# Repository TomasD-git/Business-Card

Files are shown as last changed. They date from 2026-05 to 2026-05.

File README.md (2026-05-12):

# Business-Card

> A custom dev board built inside a business card — NFC, e-paper display and 16 exposed GPIO pins.



---

## Features

- E-paper display — Configure once image stays
- NFC — tap to share Contact info, a URL, or any custom NFC
- 16 exposed GPIO pins — Connector makes it easy to use for another project
- No power design - Once flashed and configured, nfc works with no external power and image stays on e-paper screen

---

## How It Works

The Business Card is a fully custom PCB designed. The microcontroller drives both the e-paper display and the NFC IC over SPI/I2C, while the 16 GPIO pins are broken out along one edge for easy prototyping.

On power-up, the firmware initialises the display and NFC tag, can be configured, the e-paper holds whatever was last written without needing a continuous refresh.

---

## Schematic Overview

The schematic is split into four main blocks:



**MCU**: Core microcontroller, configuration of nfc and e-paper, GPIO pins   
**E-paper interface**: Has 8 exposed pins to solder an E-paper onto the PCB  
**NFC**: NFC IC with antenna matching network, presents as a standard NDEF tag  
**Power**: Power regulation with decoupling  

---

## PCB

Designed in KiCad, manufactured as a standard 2-layer board with PCBA. Gerber files and BOM are in the repo if you want to order your own.



---

<details>
  <summary>BOM</summary>

| Name | Purpose | Quantity | Total Cost (USD) | Link | Distributor |
|---|---|---|---|---|---|
| locknut | secures the screen in place with M2 bolts | 1 | 4.88 | [Link](https://www.aliexpress.com/item/32963044301.html) | Aliexpress |
| PCB + PCBA | PCB with PCBA | 2 | 73.27 | [Link](https://jlcpcb.com) | jlcpcb |
| E-Paper, 2.13" | Screen to see my name | 1 | 12.44 | [Link](https://www.aliexpress.com/item/1005005183232092.html) | Aliexpress |

</details>

<details>
  <summary>For Future</summary>

## Planned improvements

**User interface**    
Change firmware so it could be configured with web or custom application.  

**Custom CAD**  
Some type of CAD to protect mcu.  

</details>

<details>
  <summary>License</summary>

### MIT License

**Copyright (c) [2026] [TomasD-git]**

Permission is hereby granted, free of charge, to any person obtaining a copy
of this software and associated documentation files (the "Software"), to deal
in the Software without restriction, including without limitation the rights
to use, copy, modify, merge, publish, distribute, sublicense, and/or sell
copies of the Software, and to permit persons to whom the Software is
furnished to do so, subject to the following conditions:

The above copyright notice and this permission notice shall be included in all
copies or substantial portions of the Software.

THE SOFTWARE IS PROVIDED "AS IS", WITHOUT WARRANTY OF ANY KIND, EXPRESS OR
IMPLIED, INCLUDING BUT NOT LIMITED TO THE WARRANTIES OF MERCHANTABILITY,
FITNESS FOR A PARTICULAR PURPOSE AND NONINFRINGEMENT. IN NO EVENT SHALL THE
AUTHORS OR COPYRIGHT HOLDERS BE LIABLE FOR ANY CLAIM, DAMAGES OR OTHER
LIABILITY, WHETHER IN AN ACTION OF CONTRACT, TORT OR OTHERWISE, ARISING FROM,
OUT OF OR IN CONNECTION WITH THE SOFTWARE OR THE USE OR OTHER DEALINGS IN THE
SOFTWARE.

</details>

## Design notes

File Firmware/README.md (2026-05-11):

## Here you will find all firmware related stuff  
## Down here are instructions to flash the stm32  

To flash it via **usb-c** u first need to put it into **bootloader** mode, you can achive that by pluggin it in while holding boot button.  
Once in bootloader mode open **STM32CubeProgrammer**, and click connect and connect the board.  
Now pretty much done upload the **.bin** file there and flash.  

To know if it flashed sucesfully theres a small blue LED that will blink if flashed sucesfully.
Thats all.

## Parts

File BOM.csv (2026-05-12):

Name | Purpose | Quantity | Total Cost (USD) | Link | Distributor
locknut | secures the screen in place with M2 bolts | 1 | 4.88 | https://www.aliexpress.com/item/32963044301.html | Aliexpress
PCB + PCBA | PCB with PCBA | 2 | 73.27 | https://jlcpcb.com | jlcpcb
E-Paper, 2.13" | Screen to see my name | 1 | 12.44 | https://www.aliexpress.com/item/1005005183232092.html | Aliexpress

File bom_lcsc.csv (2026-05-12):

Designator | Footprint | Quantity | Value | LCSC Part #
BOOT0, NRST | SW_Push_1P1T_XKB_TS-1187A | 2 | SW_Push | C318884
C1, C3, C9 | 0402 | 3 | 1uF | C52923
C10, C11, C6 | 0603 | 3 | 10uF | C19702
C12, C13, C2, C4, C5, C7, C8 | 0402 | 7 | 100nF | C1525
D1 | 0402 | 1 | GREEN LED | C74338
D2 | 0402 | 1 | BLUE LED | C131223
J2, J3 | PinHeader_1x04_P2.54mm_Vertical | 2 | Conn_01x04_Pin
J4 | PinHeader_1x02_P2.54mm_Vertical | 1 | Conn_01x02_Pin
J5, J6 | PinSocket_1x10_P2.54mm_Vertical | 2 | Conn_01x10_Socket
J7 | USB_C_Receptacle_XKB_U262-16XN-4BVC11 | 1 | USB_C_Receptacle_USB2.0_16P | C319148
L1 | COIL_GENERATOR | 1 | L
R1, R2 | 0402 | 2 | 5.1K | C25905
R11 | 0402 | 1 | 330 | C25104
R12 | 0402 | 1 | 68 | C25758
R3, R4 | 0402 | 2 | 22 | C25092
R5, R8 | 0402 | 2 | 10K | C25744
R6, R7 | 0402 | 2 | 4.7K | C25900
U1 | QFN8P50_160X160X50L40X20N | 1 | NT3H2111W0FHKH | C710403
U2 | SOT-23-5 | 1 | AP2112K-3.3 | C51118
U3 | LQFP-48_7x7mm_P0.5mm | 1 | STM32F072C8Tx | C80488

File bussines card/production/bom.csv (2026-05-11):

Designator | Footprint | Quantity | Value | LCSC Part #
BOOT0, NRST | SW_Push_1P1T_XKB_TS-1187A | 2 | SW_Push
C1, C3, C9 | 0402 | 3 | 1uf
C10, C11, C6 | 0603 | 3 | 10uf
C12, C13, C2, C4, C5, C7, C8 | 0402 | 7 | 100nf
D1 | 0402 | 1 | GREEN LED
D2 | 0402 | 1 | BLUE LED
J2, J3 | PinHeader_1x04_P2.54mm_Vertical | 2 | Conn_01x04_Pin
J4 | PinHeader_1x02_P2.54mm_Vertical | 1 | Conn_01x02_Pin
J5, J6 | PinSocket_1x10_P2.54mm_Vertical | 2 | Conn_01x10_Socket
J7 | USB_C_Receptacle_XKB_U262-16XN-4BVC11 | 1 | USB_C_Receptacle_USB2.0_16P
L1 | COIL_GENERATOR | 1 | L
R1, R2 | 0402 | 2 | 5.1K
R11 | 0402 | 1 | 330
R12 | 0402 | 1 | 68
R3, R4 | 0402 | 2 | 22
R5, R8 | 0402 | 2 | 10K
R6, R7 | 0402 | 2 | 4.7K
U1 | QFN8P50_160X160X50L40X20N | 1 | NT3H2111W0FHKH
U2 | SOT-23-5 | 1 | AP2112K-3.3
U3 | LQFP-48_7x7mm_P0.5mm | 1 | STM32F072C8Tx

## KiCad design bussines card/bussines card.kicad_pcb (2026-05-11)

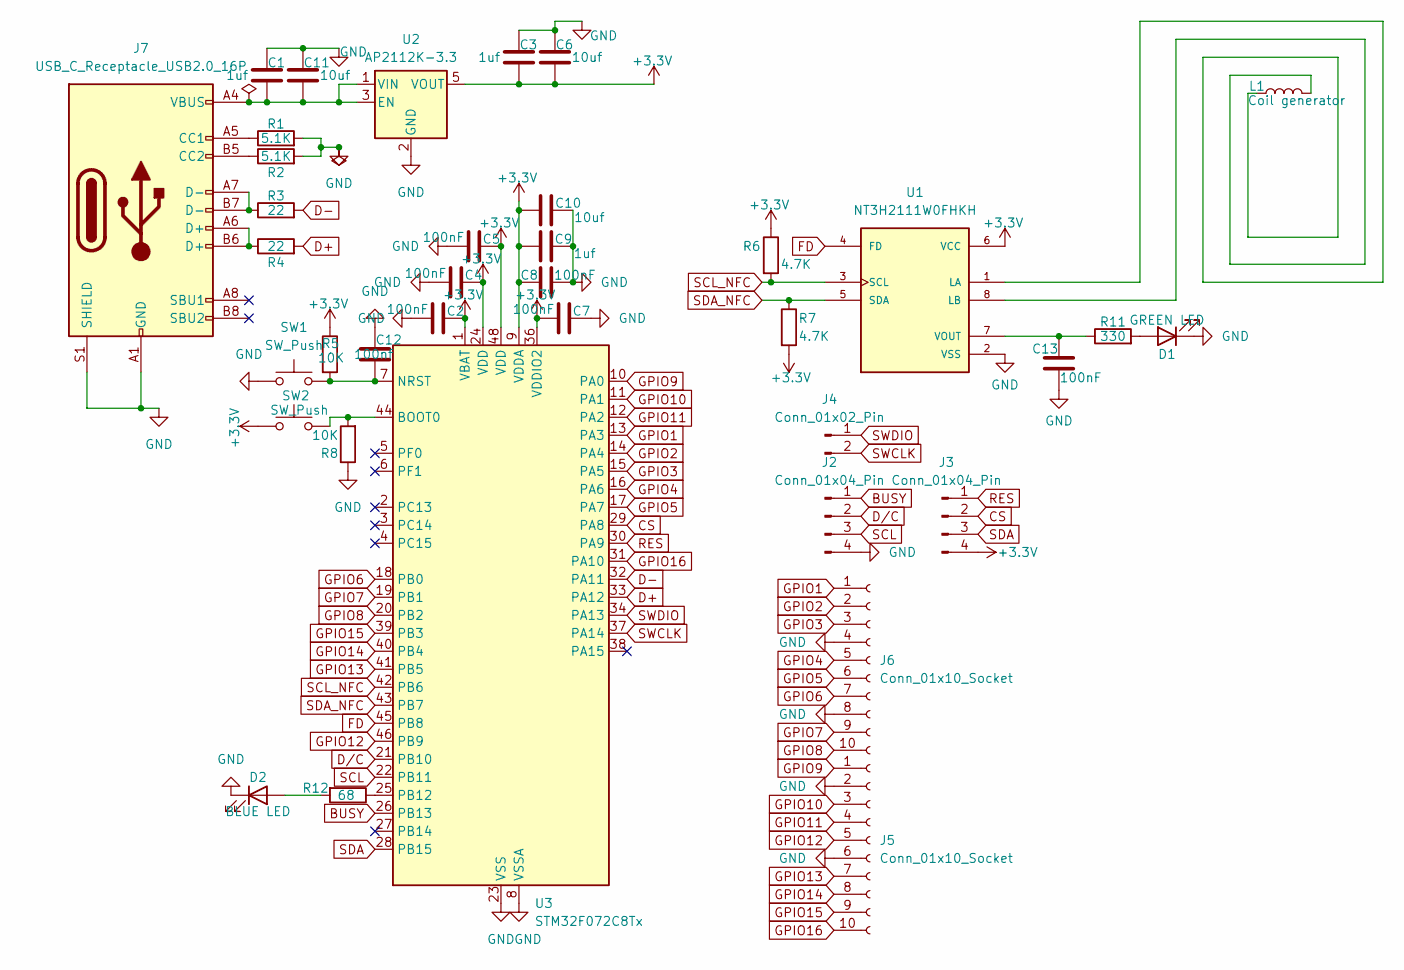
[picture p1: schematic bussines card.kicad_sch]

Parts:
C1, C3, C9: 1uf; C_0402_1005Metric
C2, C4, C5, C7, C8, C13: 100nF; C_0402_1005Metric
C6, C10, C11: 10uf; C_0603_1608Metric
C12: 100nf; C_0402_1005Metric
D1: GREEN LED; LED_0402_1005Metric
D2: BLUE LED; LED_0402_1005Metric
J2, J3: Conn_01x04_Pin; PinHeader_1x04_P2.54mm_Vertical
J4: Conn_01x02_Pin; PinHeader_1x02_P2.54mm_Vertical
J5, J6: Conn_01x10_Socket; PinSocket_1x10_P2.54mm_Vertical
J7: USB_C_Receptacle_USB2.0_16P; USB_C_Receptacle_XKB_U262-16XN-4BVC11
L1: Coil generator; COIL_GENERATOR
R1, R2: 5.1K; R_0402_1005Metric
R3, R4: 22; R_0402_1005Metric
R5, R8: 10K; R_0402_1005Metric
R6, R7: 4.7K; R_0402_1005Metric
R11: 330; R_0402_1005Metric
R12: 68; R_0402_1005Metric
SW1, SW2: SW_Push; SW_Push_1P1T_XKB_TS-1187A
U1: NT3H2111W0FHKH; QFN8P50_160X160X50L40X20N
U2: AP2112K-3.3; SOT-23-5
U3: STM32F072C8Tx; LQFP-48_7x7mm_P0.5mm

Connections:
+3.3V: C2.2, C3.2, C4.2, C5.2, C6.2, C7.1, C8.1, C9.1, C10.1, J3.4, R5.1, R6.1, R7.2, SW2.1, U1.6 (VCC), U2.5 (VOUT), U3.1 (VBAT), U3.9 (VDDA), U3.24 (VDD), U3.36 (VDDIO2), U3.48 (VDD); also elsewhere on the board
BUSY: J2.1, U3.26 (PB13)
CS: J3.2, U3.29 (PA8)
D+: R4.2, U3.33 (PA12)
D-: R3.2, U3.32 (PA11)
D/C: J2.2, U3.21 (PB10)
FD: U1.4 (FD), U3.45 (PB8)
GND: C1.1, C2.1, C3.1, C4.1, C5.1, C6.1, C7.2, C8.2, C9.2, C10.2, C11.1, C12.1, C13.1, D1.1 (K), D2.1 (K), J2.4, J5.2, J5.6, J6.4, J6.8, J7.A1 (GND), J7.A12 (GND), J7.B1 (GND), J7.B12 (GND), J7.S1 (SHIELD), R1.2, R2.2, R8.1, SW1.1, U1.2 (VSS), U2.2 (GND), U3.8 (VSSA), U3.23 (VSS), U3.35 (VSS), U3.47 (VSS); also elsewhere on the board
GPIO1: J6.1, U3.13 (PA3)
GPIO2: J6.2, U3.14 (PA4)
GPIO3: J6.3, U3.15 (PA5)
GPIO4: J6.5, U3.16 (PA6)
GPIO5: J6.6, U3.17 (PA7)
GPIO6: J6.7, U3.18 (PB0)
GPIO7: J6.9, U3.19 (PB1)
GPIO8: J6.10, U3.20 (PB2)
GPIO9: J5.1, U3.10 (PA0)
GPIO10: J5.3, U3.11 (PA1)
GPIO11: J5.4, U3.12 (PA2)
GPIO12: J5.5, U3.46 (PB9)
GPIO13: J5.7, U3.41 (PB5)
GPIO14: J5.8, U3.40 (PB4)
GPIO15: J5.9, U3.39 (PB3)
GPIO16: J5.10, U3.31 (PA10)
unnamed: D1.2 (A), R11.2
unnamed: D2.2 (A), R12.2
unnamed: J7.A5 (CC1), R1.1
unnamed: J7.B5 (CC2), R2.1
unnamed: J7.A6 (D+), J7.B6 (D+), R4.1
unnamed: J7.A7 (D-), J7.B7 (D-), R3.1
unnamed: L1.1, U1.1 (LA)
unnamed: L1.2, U1.8 (LB)
unnamed: C13.2, R11.1, U1.7 (VOUT)
unnamed: C1.2, C11.2, J7.A4 (VBUS), J7.A9 (VBUS), J7.B4 (VBUS), J7.B9 (VBUS), U2.1 (VIN), U2.3 (EN)
unnamed 34: R8.2, SW2.2, U3.44 (BOOT0); also elsewhere on the board
unnamed 35: C12.2, R5.2, SW1.2, U3.7 (NRST); also elsewhere on the board
unnamed: R12.1, U3.25 (PB12)
RES: J3.1, U3.30 (PA9)
SCL: J2.3, U3.22 (PB11)
SCL_NFC: R6.2, U1.3 (SCL), U3.42 (PB6)
SDA: J3.3, U3.28 (PB15)
SDA_NFC: R7.1, U1.5 (SDA), U3.43 (PB7)
SWCLK: J4.2, U3.37 (PA14)
SWDIO: J4.1, U3.34 (PA13)

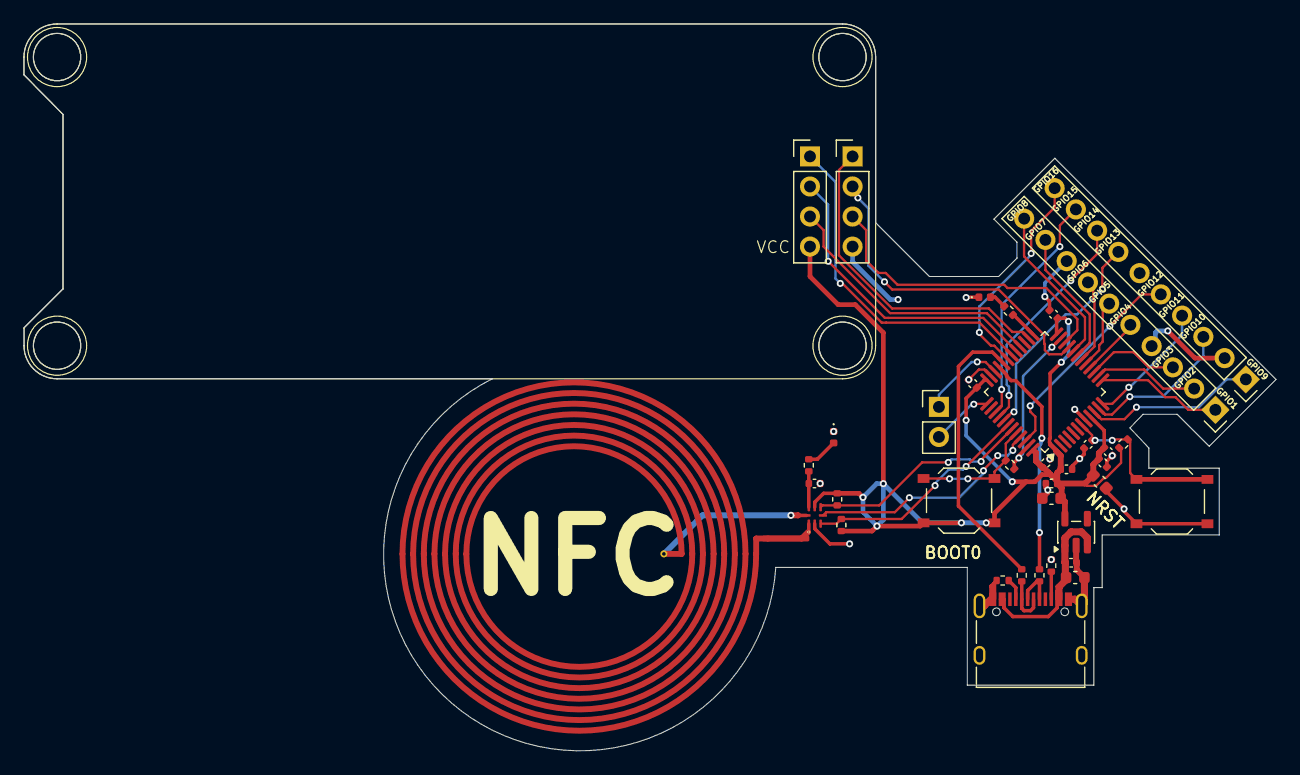
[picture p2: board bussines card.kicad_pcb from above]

Board: 2 copper layers, 105.9 x 61.4 mm, 37 parts (0 on the bottom side), 44 nets.

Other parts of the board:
BOOT0: SW_Push; SW_Push_1P1T_XKB_TS-1187A
NRST: SW_Push; SW_Push_1P1T_XKB_TS-1187A

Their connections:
+3.3V: BOOT0.1; also elsewhere on the board
GND: NRST.1; also elsewhere on the board
unnamed 34: BOOT0.2; also elsewhere on the board
unnamed 35: NRST.2; also elsewhere on the board

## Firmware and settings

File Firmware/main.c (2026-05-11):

#include "stm32f0xx_hal.h"
#include <string.h>
#include <stdint.h>

#define MY_EMAIL   "thomasdvorak76@gmail.com" //set this to your email address before building


/* E-Paper */
#define EPD_CLK_PORT   GPIOB
#define EPD_CLK_PIN    GPIO_PIN_11

#define EPD_DIN_PORT   GPIOB
#define EPD_DIN_PIN    GPIO_PIN_15

#define EPD_CS_PORT    GPIOA
#define EPD_CS_PIN     GPIO_PIN_8

#define EPD_DC_PORT    GPIOB
#define EPD_DC_PIN     GPIO_PIN_10

#define EPD_RST_PORT   GPIOA
#define EPD_RST_PIN    GPIO_PIN_9

#define EPD_BSY_PORT   GPIOB
#define EPD_BSY_PIN    GPIO_PIN_13

/* ── NFC ── */
#define NTAG_ADDR      (0x55u << 1)   

/* Blue LED */
#define LED_B_PORT     GPIOB
#define LED_B_PIN      GPIO_PIN_12

#define EPD_W          250
#define EPD_H          122
#define EPD_BPR        16                  
#define EPD_BUFSZ      (EPD_W * EPD_BPR) 

static uint8_t g_fb[EPD_BUFSZ];


static const uint8_t FONT[5][16] = {
    /* T */ { 0xFF,0x18,0x18,0x18,0x18,0x18,0x18,0x18,
              0x18,0x18,0x18,0x18,0x18,0x00,0x00,0x00 },
    /* o */ { 0x00,0x00,0x3C,0x66,0x66,0x66,0x66,0x66,
              0x66,0x3C,0x00,0x00,0x00,0x00,0x00,0x00 },
    /* m */ { 0x00,0x00,0x6C,0x7E,0x76,0x66,0x66,0x66,
              0x66,0x66,0x00,0x00,0x00,0x00,0x00,0x00 },
    /* a */ { 0x00,0x00,0x3E,0x60,0x60,0x7E,0x66,0x66,
              0x66,0x7E,0x00,0x00,0x00,0x00,0x00,0x00 },
    /* s */ { 0x00,0x00,0x3C,0x66,0x06,0x1C,0x38,0x60,
              0x66,0x3C,0x00,0x00,0x00,0x00,0x00,0x00 },
};
static I2C_HandleTypeDef hi2c1;


static void SystemClock_Config(void);
static void GPIO_Init(void);
static void I2C1_Init(void);

/* e-paper */
static void epd_spi_byte(uint8_t b);
static void epd_cmd(uint8_t c);
static void epd_dat(uint8_t d);
static void epd_busy_wait(void);
static void epd_hw_reset(void);
static void epd_init(void);
static void epd_clear_fb(uint8_t colour);   
static void epd_set_px(int x, int y);        
static void epd_draw_rect(int x, int y, int w, int h, int thick);
static void epd_draw_glyph(int x, int y, int gi, int sc);
static void epd_flush(void);
static void epd_sleep(void);

/* NFC */
static void ntag_write_ndef_email(const char *email);

/* Blue LED */
static void led_success_sequence(void);

/*  MAIN  */
int main(void)
{
    HAL_Init();
    SystemClock_Config();
    GPIO_Init();
    I2C1_Init();

    const int SC   = 3;
    const int GW   = 8  * SC;           
    const int GH   = 16 * SC;        
    const int GAP  = 3;
    const int tx   = (EPD_W - (5 * GW + 4 * GAP)) / 2; 
    const int ty   = (EPD_H - GH) / 2;              

    epd_clear_fb(0xFF);                 

    for (int i = 0; i < 5; i++)
        epd_draw_glyph(tx + i * (GW + GAP), ty, i, SC);

    epd_draw_rect(0, 0, EPD_W, EPD_H, 2);

    epd_init();
    epd_flush();
    epd_sleep();  

    ntag_write_ndef_email(MY_EMAIL);

    led_success_sequence();


    while (1)
        __WFI();  
}


static void SystemClock_Config(void)
{
    RCC_OscInitTypeDef osc = {0};
    RCC_ClkInitTypeDef clk = {0};

    osc.OscillatorType = RCC_OSCILLATORTYPE_HSI48;
    osc.HSI48State     = RCC_HSI48_ON;
    osc.PLL.PLLState   = RCC_PLL_NONE;
    if (HAL_RCC_OscConfig(&osc) != HAL_OK) { while(1); }

    clk.ClockType      = RCC_CLOCKTYPE_HCLK | RCC_CLOCKTYPE_SYSCLK
                       | RCC_CLOCKTYPE_PCLK1;
    clk.SYSCLKSource   = RCC_SYSCLKSOURCE_HSI48;
    clk.AHBCLKDivider  = RCC_SYSCLK_DIV1;
    clk.APB1CLKDivider = RCC_HCLK_DIV1;
    if (HAL_RCC_ClockConfig(&clk, FLASH_LATENCY_1) != HAL_OK) { while(1); }
}


static void GPIO_Init(void)
{
    __HAL_RCC_GPIOA_CLK_ENABLE();
    __HAL_RCC_GPIOB_CLK_ENABLE();

    GPIO_InitTypeDef g = {0};
    g.Mode  = GPIO_MODE_OUTPUT_PP;
    g.Pull  = GPIO_NOPULL;
    g.Speed = GPIO_SPEED_FREQ_HIGH;

    g.Pin = EPD_CLK_PIN;  HAL_GPIO_Init(EPD_CLK_PORT, &g);
    g.Pin = EPD_DIN_PIN;  HAL_GPIO_Init(EPD_DIN_PORT, &g);
    g.Pin = EPD_DC_PIN;   HAL_GPIO_Init(EPD_DC_PORT,  &g);

    g.Pin = EPD_CS_PIN;   HAL_GPIO_Init(EPD_CS_PORT,  &g);
    g.Pin = EPD_RST_PIN;  HAL_GPIO_Init(EPD_RST_PORT, &g);

    g.Pin = LED_B_PIN;    HAL_GPIO_Init(LED_B_PORT,   &g);

    g.Mode = GPIO_MODE_INPUT;
    g.Pull = GPIO_PULLUP;
    g.Pin  = EPD_BSY_PIN; HAL_GPIO_Init(EPD_BSY_PORT, &g);

    g.Pin = GPIO_PIN_8;   HAL_GPIO_Init(GPIOB,        &g);

    HAL_GPIO_WritePin(EPD_CS_PORT,  EPD_CS_PIN,  GPIO_PIN_SET);   
    HAL_GPIO_WritePin(EPD_RST_PORT, EPD_RST_PIN, GPIO_PIN_SET);  
    HAL_GPIO_WritePin(EPD_CLK_PORT, EPD_CLK_PIN, GPIO_PIN_RESET);
    HAL_GPIO_WritePin(LED_B_PORT,   LED_B_PIN,   GPIO_PIN_RESET); 
}

static void I2C1_Init(void)
{
    __HAL_RCC_I2C1_CLK_ENABLE();

    GPIO_InitTypeDef g = {0};
    g.Pin       = GPIO_PIN_6 | GPIO_PIN_7;
    g.Mode      = GPIO_MODE_AF_OD;
    g.Pull      = GPIO_NOPULL; 
    g.Speed     = GPIO_SPEED_FREQ_HIGH;
    g.Alternate = GPIO_AF1_I2C1;
    HAL_GPIO_Init(GPIOB, &g);

    hi2c1.Instance             = I2C1;
    hi2c1.Init.Timing          = 0x2000090E; 
    hi2c1.Init.OwnAddress1     = 0;
    hi2c1.Init.AddressingMode  = I2C_ADDRESSINGMODE_7BIT;
    hi2c1.Init.DualAddressMode = I2C_DUALADDRESS_DISABLE;
    hi2c1.Init.GeneralCallMode = I2C_GENERALCALL_DISABLE;
    hi2c1.Init.NoStretchMode   = I2C_NOSTRETCH_DISABLE;
    if (HAL_I2C_Init(&hi2c1) != HAL_OK) { while(1); }
}



static inline void epd_cs_low(void)
{ HAL_GPIO_WritePin(EPD_CS_PORT, EPD_CS_PIN, GPIO_PIN_RESET); }

static inline void epd_cs_high(void)
{ HAL_GPIO_WritePin(EPD_CS_PORT, EPD_CS_PIN, GPIO_PIN_SET); }

static void epd_spi_byte(uint8_t b)
{
  
    for (int8_t i = 7; i >= 0; i--) {
        HAL_GPIO_WritePin(EPD_CLK_PORT, EPD_CLK_PIN, GPIO_PIN_RESET);
        HAL_GPIO_WritePin(EPD_DIN_PORT, EPD_DIN_PIN,
                          ((b >> i) & 1u) ? GPIO_PIN_SET : GPIO_PIN_RESET);
        HAL_GPIO_WritePin(EPD_CLK_PORT, EPD_CLK_PIN, GPIO_PIN_SET);
    }
}

static void epd_cmd(uint8_t c)
{
    HAL_GPIO_WritePin(EPD_DC_PORT, EPD_DC_PIN, GPIO_PIN_RESET);
    epd_cs_low();
    epd_spi_byte(c);
    epd_cs_high();
}

static void epd_dat(uint8_t d)
{
    HAL_GPIO_WritePin(EPD_DC_PORT, EPD_DC_PIN, GPIO_PIN_SET);  
    epd_cs_low();
    epd_spi_byte(d);
    epd_cs_high();
}

static void epd_busy_wait(void)
{
    uint32_t t = HAL_GetTick();
    while (HAL_GPIO_ReadPin(EPD_BSY_PORT, EPD_BSY_PIN) == GPIO_PIN_SET) {
        if ((HAL_GetTick() - t) > 5000) break;  
        HAL_Delay(5);
    }
}

static void epd_hw_reset(void)
{
    HAL_GPIO_WritePin(EPD_RST_PORT, EPD_RST_PIN, GPIO_PIN_SET);
    HAL_Delay(20);
    HAL_GPIO_WritePin(EPD_RST_PORT, EPD_RST_PIN, GPIO_PIN_RESET);
    HAL_Delay(5);
    HAL_GPIO_WritePin(EPD_RST_PORT, EPD_RST_PIN, GPIO_PIN_SET);
    HAL_Delay(20);
}

static void epd_init(void)
{
    epd_hw_reset();

    epd_cmd(0x12);         
    HAL_Delay(10);
    epd_busy_wait();

    epd_cmd(0x01);
    epd_dat(0xF9);          
    epd_dat(0x00);      
    epd_dat(0x00);     

    epd_cmd(0x11);
    epd_dat(0x03);

    epd_cmd(0x44);
    epd_dat(0x00);
    epd_dat(EPD_BPR - 1); 

    epd_cmd(0x45);
    epd_dat(0x00); epd_dat(0x00);      
    epd_dat((EPD_W - 1) & 0xFF);      
    epd_dat((EPD_W - 1) >> 8);       

    epd_cmd(0x3C);
    epd_dat(0x05);

    epd_cmd(0x21);
    epd_dat(0x00);
    epd_dat(0x80);

    epd_cmd(0x18);
    epd_dat(0x80);

    epd_busy_wait();
}

static void epd_clear_fb(uint8_t colour)
{
    memset(g_fb, colour, EPD_BUFSZ);
}


static void epd_set_px(int x, int y)
{
    if ((unsigned)x >= EPD_W || (unsigned)y >= EPD_H) return;
    int idx = x * EPD_BPR + (y >> 3);
    int bit = 7 - (y & 7);
    g_fb[idx] &= ~(1u << bit);   
}

static void epd_draw_rect(int x, int y, int w, int h, int thick)
{
    for (int t = 0; t < thick; t++) {
        for (int i = x + t; i < x + w - t; i++) {
            epd_set_px(i, y + t);
            epd_set_px(i, y + h - 1 - t);
        }
        for (int j = y + t; j < y + h - t; j++) {
            epd_set_px(x + t,         j);
            epd_set_px(x + w - 1 - t, j);
        }
    }
}

static void epd_draw_glyph(int px, int py, int gi, int sc)
{
    for (int row = 0; row < 16; row++) {
        uint8_t bits = FONT[gi][row];
        for (int col = 0; col < 8; col++) {
            if (bits & (0x80u >> col)) {
                for (int sy = 0; sy < sc; sy++)
                    for (int sx = 0; sx < sc; sx++)
                        epd_set_px(px + col * sc + sx,
                                   py + row * sc + sy);
            }
        }
    }
}

static void epd_flush(void)
{
    epd_cmd(0x4E); epd_dat(0x00);
    epd_cmd(0x4F); epd_dat(0x00); epd_dat(0x00);
    epd_busy_wait();

    epd_cmd(0x24);
    for (uint32_t i = 0; i < EPD_BUFSZ; i++)
        epd_dat(g_fb[i]);
    epd_cmd(0x22);
    epd_dat(0xF7);
    epd_cmd(0x20);
    epd_busy_wait();
}

static void epd_sleep(void)
{
    epd_cmd(0x10);
    epd_dat(0x01);
    HAL_Delay(100);
}
/*  NFC  */
static void ntag_write_ndef_email(const char *email)
{
    const uint8_t elen        = (uint8_t)strlen(email);
    const uint8_t payload_len = 1u + elen;        
    const uint8_t ndef_len    = 4u + payload_len;  

    uint8_t msg[72];
    uint8_t pos = 0;

    msg[pos++] = 0x03;        
    msg[pos++] = ndef_len;      
    msg[pos++] = 0xD1;         
    msg[pos++] = 0x01;       
    msg[pos++] = payload_len;   
    msg[pos++] = 'U';           
    msg[pos++] = 0x06;          

    for (uint8_t i = 0; i < elen; i++)
        msg[pos++] = (uint8_t)email[i];

    msg[pos++] = 0xFE;      

    uint8_t blk = 0x01;
    uint8_t src = 0;

    while (src < pos) {
        uint8_t pkt[17];
        pkt[0] = blk;
        memset(&pkt[1], 0x00, 16);

        for (uint8_t i = 1; i <= 16 && src < pos; i++, src++)
            pkt[i] = msg[src];

        for (int retry = 0; retry < 3; retry++) {
            if (HAL_I2C_Master_Transmit(&hi2c1, NTAG_ADDR,
                                        pkt, 17, 50) == HAL_OK) break;
            HAL_Delay(2);
        }
        HAL_Delay(6);   
        blk++;
    }
}

static void led_success_sequence(void)
{
    for (int i = 0; i < 2; i++) {
        HAL_GPIO_WritePin(LED_B_PORT, LED_B_PIN, GPIO_PIN_SET);
        HAL_Delay(1000);
        HAL_GPIO_WritePin(LED_B_PORT, LED_B_PIN, GPIO_PIN_RESET);
        HAL_Delay(1000);
    }
    HAL_GPIO_WritePin(LED_B_PORT, LED_B_PIN, GPIO_PIN_SET);
}

void HAL_MspInit(void)
{
    __HAL_RCC_SYSCFG_CLK_ENABLE();
    __HAL_RCC_PWR_CLK_ENABLE();
}

void SysTick_Handler(void)
{
    HAL_IncTick();
}

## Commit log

2026-05-11 Add firmware flashing instructions to README
    Added instructions for flashing STM32 firmware via USB-C.
2026-05-11 added KiCad files
    [bom.csv, bussines card.kicad_pcb, bussines card.kicad_sch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]
2026-05-12 added main files for PCBA
    [bom_lcsc.csv]
2026-05-12 Revise README for clarity and additional details
    Updated the README to provide a clearer description and detailed features of the Business Card project, including how it works, schematic overview, PCB design, BOM, planned improvements, and license 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
